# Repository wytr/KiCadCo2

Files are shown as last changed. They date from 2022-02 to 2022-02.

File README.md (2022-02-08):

# KiCadCo2

# ESP 12-F | MH-Z19C | CO2 INDICATOR

Schematic [here](https://github.com/wytr/KiCadCo2/blob/master/schematic_pdf/ESP8266_12F_BASIC.pdf)

Assembly [here](https://github.com/wytr/KiCadCo2/blob/master/Board2Pdf/ESP8266_12F_BASIC-Assembly.pdf)

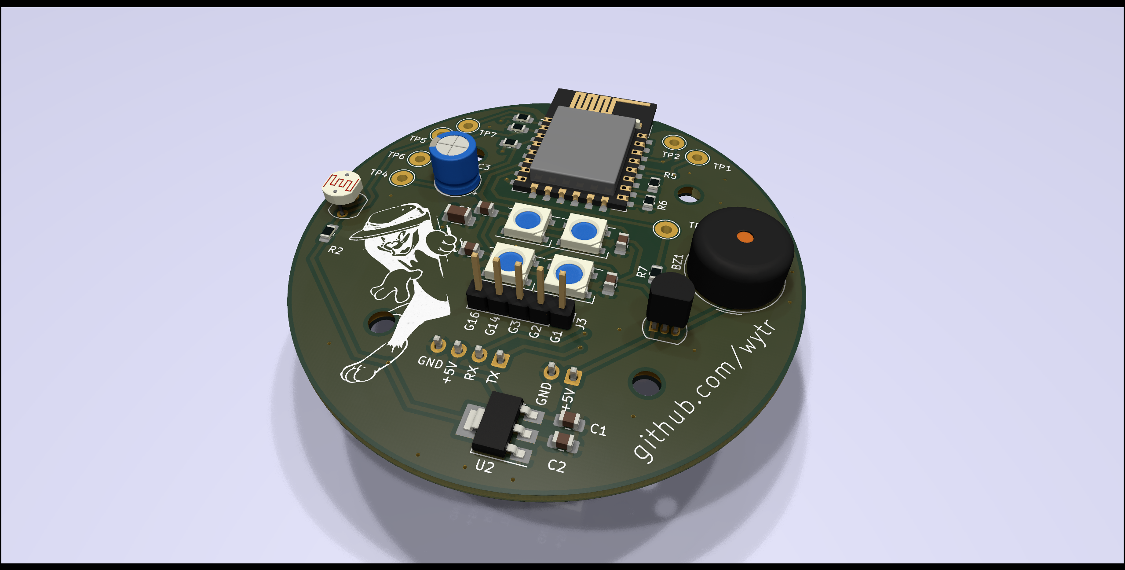
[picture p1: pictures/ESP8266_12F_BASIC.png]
raytraced pcb


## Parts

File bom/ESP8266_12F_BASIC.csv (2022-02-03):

Source: | C:\Users\mrtn\Documents\KiCad\6.0\projects\ESP8266_12F_BASIC\ESP8266_12F_BASIC.kicad_sch
Date: | 03.02.2022 03:34:38
Tool: | Eeschema (6.0.1)
Generator: | C:\Program Files\KiCad\6.0\bin\scripting\plugins/bom_csv_grouped_by_value.py
Component Count: | 35
Individual Components:
Item | Qty | Reference(s) | Value | LibPart | Footprint | Datasheet
 |  | BZ1 | Buzzer | Device:Buzzer | Buzzer_Beeper:Buzzer_TDK_PS1240P02BT_D12.2mm_H6.5mm | ~
 |  | C1 | 100nF | Device:C_Small | Capacitor_SMD:C_0805_2012Metric_Pad1.18x1.45mm_HandSolder | ~
 |  | C2 | 100nF | Device:C_Small | Capacitor_SMD:C_0805_2012Metric_Pad1.18x1.45mm_HandSolder | ~
 |  | C3 | 10uF | Device:C | Capacitor_THT:CP_Radial_D6.3mm_P2.50mm | ~
 |  | C5 | 100nF | Device:C_Small | Capacitor_SMD:C_0805_2012Metric_Pad1.18x1.45mm_HandSolder | ~
 |  | C6 | 100nF | Device:C_Small | Capacitor_SMD:C_0805_2012Metric_Pad1.18x1.45mm_HandSolder | ~
 |  | C7 | 100nF | Device:C_Small | Capacitor_SMD:C_0805_2012Metric_Pad1.18x1.45mm_HandSolder | ~
 |  | C8 | 100nF | Device:C_Small | Capacitor_SMD:C_0805_2012Metric_Pad1.18x1.45mm_HandSolder | ~
 |  | D1 | WS2812B | LED:WS2812B | LED_SMD:LED_WS2812B_PLCC4_5.0x5.0mm_P3.2mm | https://cdn-shop.adafruit.com/datasheets/WS2812B.pdf
 |  | D2 | WS2812B | LED:WS2812B | LED_SMD:LED_WS2812B_PLCC4_5.0x5.0mm_P3.2mm | https://cdn-shop.adafruit.com/datasheets/WS2812B.pdf
 |  | D3 | WS2812B | LED:WS2812B | LED_SMD:LED_WS2812B_PLCC4_5.0x5.0mm_P3.2mm | https://cdn-shop.adafruit.com/datasheets/WS2812B.pdf
 |  | D4 | WS2812B | LED:WS2812B | LED_SMD:LED_WS2812B_PLCC4_5.0x5.0mm_P3.2mm | https://cdn-shop.adafruit.com/datasheets/WS2812B.pdf
 |  | H1 | MountingHole | Mechanical:MountingHole | MountingHole:MountingHole_3.2mm_M3 | ~
 |  | H2 | MountingHole | Mechanical:MountingHole | MountingHole:MountingHole_3.2mm_M3 | ~
 |  | H3 | MountingHole | Mechanical:MountingHole | MountingHole:MountingHole_3.2mm_M3 | ~
 |  | H4 | MountingHole | Mechanical:MountingHole | MountingHole:MountingHole_3.2mm_M3 | ~
 |  | J1 | Conn_01x02_Male | Connector:Conn_01x02_Male | Connector_JST:JST_XH_B2B-XH-A_1x02_P2.50mm_Vertical | ~
 |  | J2 | Conn_01x04_Male | Connector:Conn_01x04_Male | Connector_JST:JST_XH_B4B-XH-A_1x04_P2.50mm_Vertical | ~
 |  | Q1 | BC547 | Transistor_BJT:BC547 | Package_TO_SOT_THT:TO-92_Inline | https://www.onsemi.com/pub/Collateral/BC550-D.pdf
 |  | R1 | R_Photo | Device:R_Photo | OptoDevice:R_LDR_5.1x4.3mm_P3.4mm_Vertical | ~
 |  | R2 | 100k | Device:R | Resistor_SMD:R_0805_2012Metric_Pad1.20x1.40mm_HandSolder | ~
 |  | R3 | 10k | Device:R_Small | Resistor_SMD:R_0805_2012Metric_Pad1.20x1.40mm_HandSolder | ~
 |  | R4 | 10k | Device:R_Small | Resistor_SMD:R_0805_2012Metric_Pad1.20x1.40mm_HandSolder | ~
 |  | R5 | 10k | Device:R_Small | Resistor_SMD:R_0805_2012Metric_Pad1.20x1.40mm_HandSolder | ~
 |  | R6 | 10k | Device:R_Small | Resistor_SMD:R_0805_2012Metric_Pad1.20x1.40mm_HandSolder | ~
 |  | R7 | 100R | Device:R_Small | Resistor_SMD:R_0805_2012Metric_Pad1.20x1.40mm_HandSolder | ~
 |  | TP1 | TestPoint | Connector:TestPoint | TestPoint:TestPoint_THTPad_D3.0mm_Drill1.5mm | ~
 |  | TP2 | TestPoint | Connector:TestPoint | TestPoint:TestPoint_THTPad_D3.0mm_Drill1.5mm | ~
 |  | TP3 | TestPoint | Connector:TestPoint | TestPoint:TestPoint_THTPad_D3.0mm_Drill1.5mm | ~
 |  | TP4 | TestPoint | Connector:TestPoint | TestPoint:TestPoint_THTPad_D3.0mm_Drill1.5mm | ~
 |  | TP5 | TestPoint | Connector:TestPoint | TestPoint:TestPoint_THTPad_D3.0mm_Drill1.5mm | ~
 |  | TP6 | TestPoint | Connector:TestPoint | TestPoint:TestPoint_THTPad_D3.0mm_Drill1.5mm | ~
 |  | TP7 | TestPoint | Connector:TestPoint | TestPoint:TestPoint_THTPad_D3.0mm_Drill1.5mm | ~
 |  | U1 | ESP-12F | RF_Module:ESP-12F | RF_Module:ESP-12E | http://wiki.ai-thinker.com/_media/esp8266/esp8266_series_modules_user_manual_v1.1.pdf
 |  | U2 | AP1117-33 | Regulator_Linear:AP1117-33 | Package_TO_SOT_SMD:SOT-223-3_TabPin2 | http://www.diodes.com/datasheets/AP1117.pdf
Collated Components:
Item | Qty | Reference(s) | Value | LibPart | Footprint | Datasheet
1 | 1 | BZ1 | Buzzer | Device:Buzzer | Buzzer_Beeper:Buzzer_TDK_PS1240P02BT_D12.2mm_H6.5mm | ~
2 | 6 | C1, C2, C5, C6, C7, C8 | 100nF | Device:C_Small | Capacitor_SMD:C_0805_2012Metric_Pad1.18x1.45mm_HandSolder | ~
3 | 1 | C3 | 10uF | Device:C | Capacitor_THT:CP_Radial_D6.3mm_P2.50mm | ~
4 | 4 | D1, D2, D3, D4 | WS2812B | LED:WS2812B | LED_SMD:LED_WS2812B_PLCC4_5.0x5.0mm_P3.2mm | https://cdn-shop.adafruit.com/datasheets/WS2812B.pdf
5 | 4 | H1, H2, H3, H4 | MountingHole | Mechanical:MountingHole | MountingHole:MountingHole_3.2mm_M3 | ~
6 | 1 | J1 | Conn_01x02_Male | Connector:Conn_01x02_Male | Connector_JST:JST_XH_B2B-XH-A_1x02_P2.50mm_Vertical | ~
7 | 1 | J2 | Conn_01x04_Male | Connector:Conn_01x04_Male | Connector_JST:JST_XH_B4B-XH-A_1x04_P2.50mm_Vertical | ~
8 | 1 | Q1 | BC547 | Transistor_BJT:BC547 | Package_TO_SOT_THT:TO-92_Inline | https://www.onsemi.com/pub/Collateral/BC550-D.pdf
9 | 1 | R1 | R_Photo | Device:R_Photo | OptoDevice:R_LDR_5.1x4.3mm_P3.4mm_Vertical | ~
10 | 1 | R2 | 100k | Device:R | Resistor_SMD:R_0805_2012Metric_Pad1.20x1.40mm_HandSolder | ~
11 | 4 | R3, R4, R5, R6 | 10k | Device:R_Small | Resistor_SMD:R_0805_2012Metric_Pad1.20x1.40mm_HandSolder | ~
12 | 1 | R7 | 100R | Device:R_Small | Resistor_SMD:R_0805_2012Metric_Pad1.20x1.40mm_HandSolder | ~
13 | 7 | TP1, TP2, TP3, TP4, TP5, TP6, TP7 | TestPoint | Connector:TestPoint | TestPoint:TestPoint_THTPad_D3.0mm_Drill1.5mm | ~
14 | 1 | U1 | ESP-12F | RF_Module:ESP-12F | RF_Module:ESP-12E | http://wiki.ai-thinker.com/_media/esp8266/esp8266_series_modules_user_manual_v1.1.pdf
15 | 1 | U2 | AP1117-33 | Regulator_Linear:AP1117-33 | Package_TO_SOT_SMD:SOT-223-3_TabPin2 | http://www.diodes.com/datasheets/AP1117.pdf

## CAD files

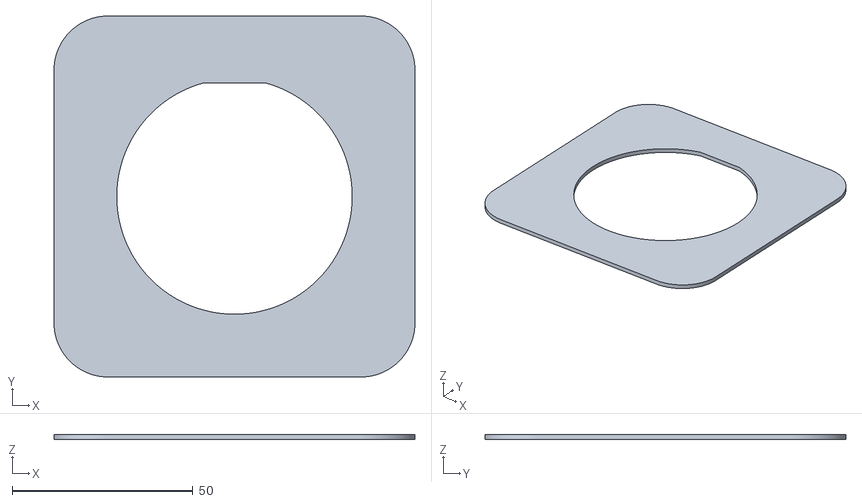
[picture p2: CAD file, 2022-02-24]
3D_MODEL/Schablonenhalter.stl
100.0 x 100.0 x 1.50

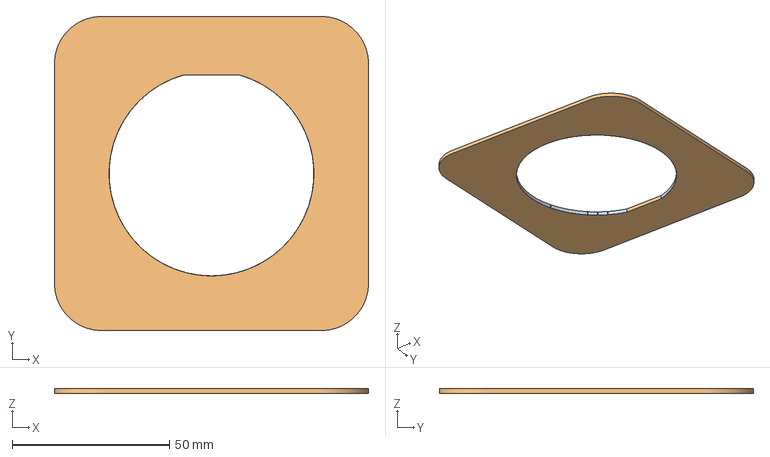
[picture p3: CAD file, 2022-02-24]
3D_MODEL/ESP8266_12F_CO2_Schablonenhalter.FCStd
100.0 x 100.0 x 1.50 mm
Part (Meshed)

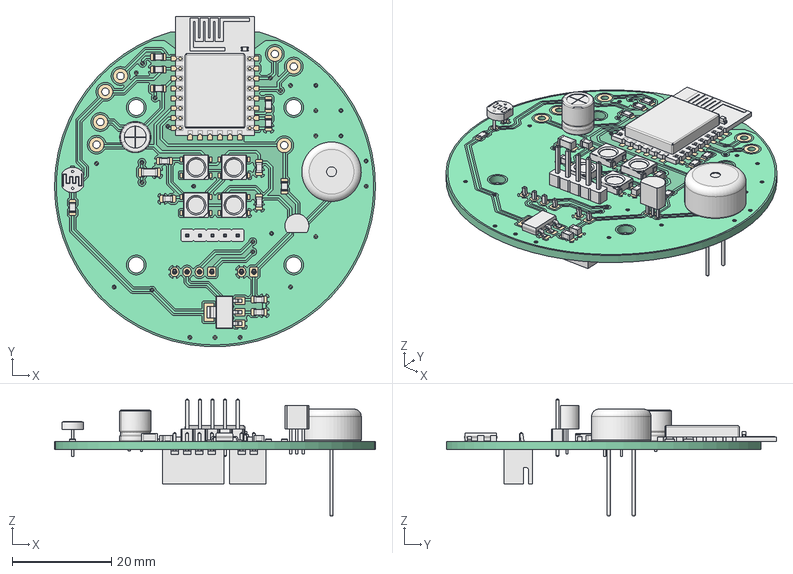
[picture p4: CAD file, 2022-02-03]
3D_MODEL/ESP8266_12F_CO2.FCStd
64.7 x 66.5 x 23.5 mm
Pcb_7f20
topPads_7f20
topTracks_7f20
topZones_7f20
botPads_7f20
botTracks_7f20
botZones_7f20
R4_R_0805_2012Metric_5a90df88a964 x 7
D2_LED_WS2812B_PLCC4_50x50mm_P32mm_d242eb3a4c77 x 4
U2_SOT_223_ae3f01b72ff0
C4_C_1206_3216Metric_41223b271484
C3_CP_Radial_D63mm_P250mm_c3d035a31bd0
J3_PinHeader_1x05_P254mm_Vertical_2d5c8401fe23
C5_C_0805_2012Metric_72cb813c9184 x 6
R1_R_LDR_5.1x4.3mm_P3.4mm_Vertical_380525c35caf
Q1_TO-92_Inline_Narrow_ab2950cb5ffa
U1_ESP_12E001_cp_c43c0a32ca6d
BZ1_Buzzer_TDK_PS1240P02BT_D122mm_H65mm_4825805f86ed
J1_JST_B2B_XH_A_3523783868fa
J2_JST_B4B_XH_A_3fdb70fe1788

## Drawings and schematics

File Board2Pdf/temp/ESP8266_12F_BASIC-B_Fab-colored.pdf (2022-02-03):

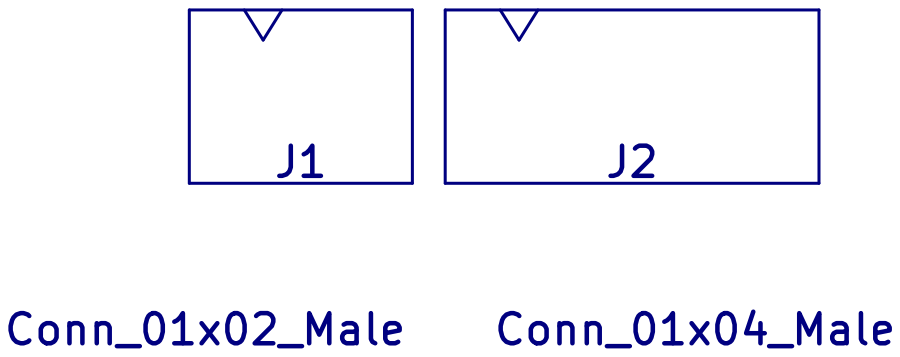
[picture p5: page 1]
D Date: KiCad E.D.A. kicad (6.0.1) Size: A4; Rev:; Id: 1/1 Title:; File: ESP8266_12F_BASIC.kicad_pcb; Sheet: Assembly; Conn_01x02_Male; Conn_01x04_Male

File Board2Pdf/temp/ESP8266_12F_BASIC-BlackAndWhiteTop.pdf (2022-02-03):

1 | 2 | 3 | 4 | 5 | 6

A

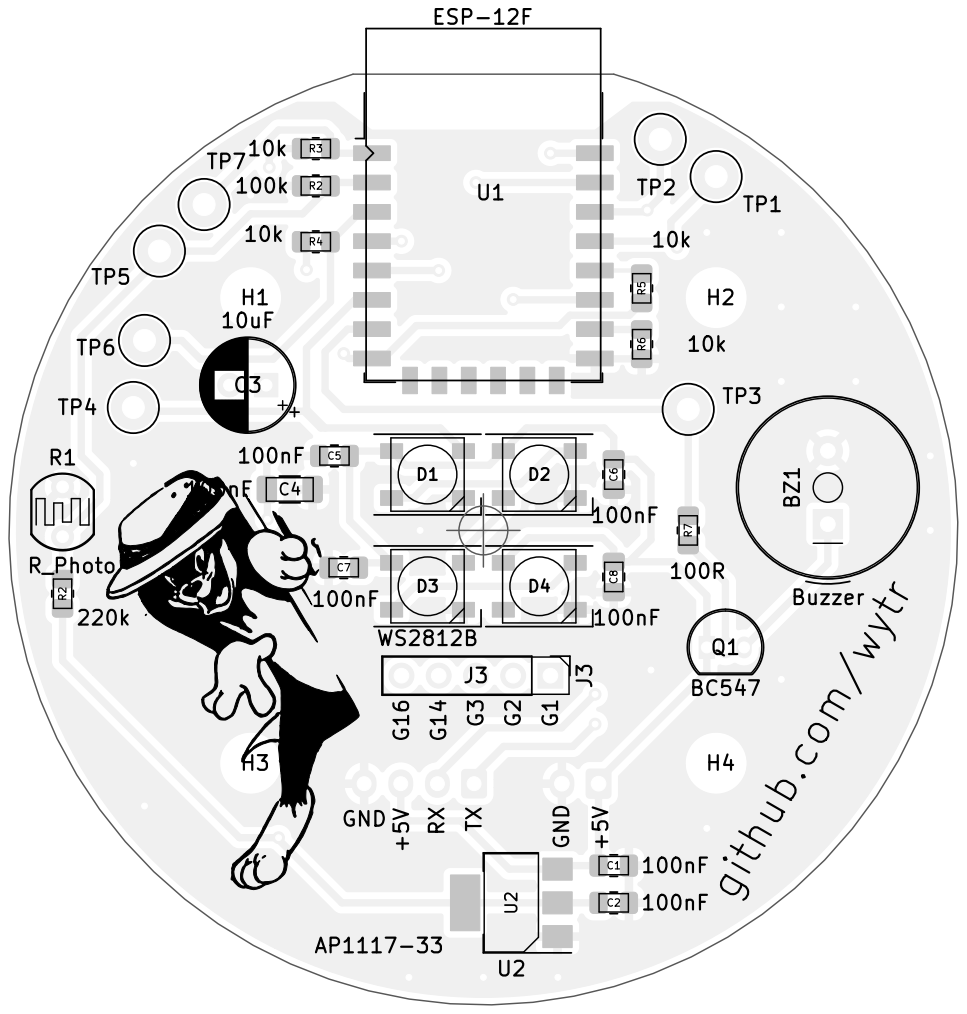
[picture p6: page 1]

G1 RXTX G3 G2 G14 GND github.com/wytr +5V G16 +5V GND

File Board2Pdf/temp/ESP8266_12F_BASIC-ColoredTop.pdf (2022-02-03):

1 | 2 | 3 | 4 | 5 | 6

A

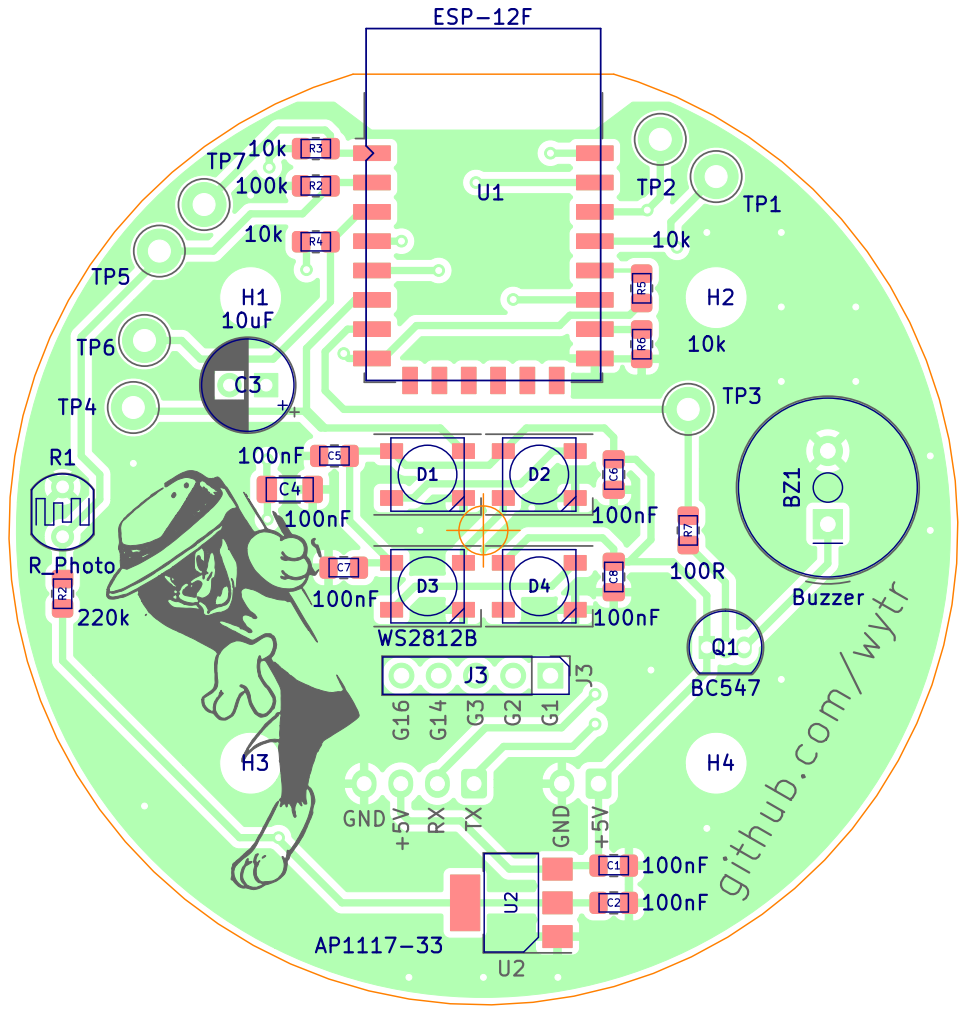
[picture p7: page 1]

G1 RXTX G3 G2 G14 GND github.com/wytr +5V G16 +5V GND

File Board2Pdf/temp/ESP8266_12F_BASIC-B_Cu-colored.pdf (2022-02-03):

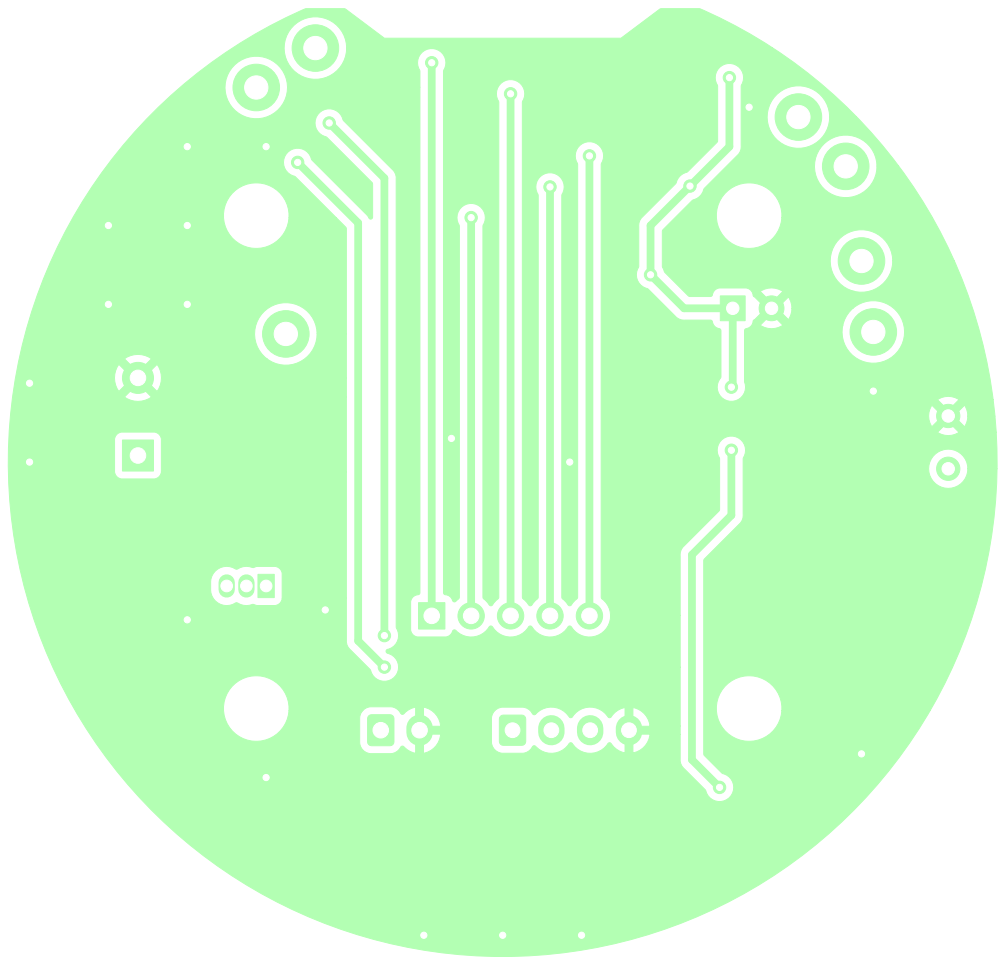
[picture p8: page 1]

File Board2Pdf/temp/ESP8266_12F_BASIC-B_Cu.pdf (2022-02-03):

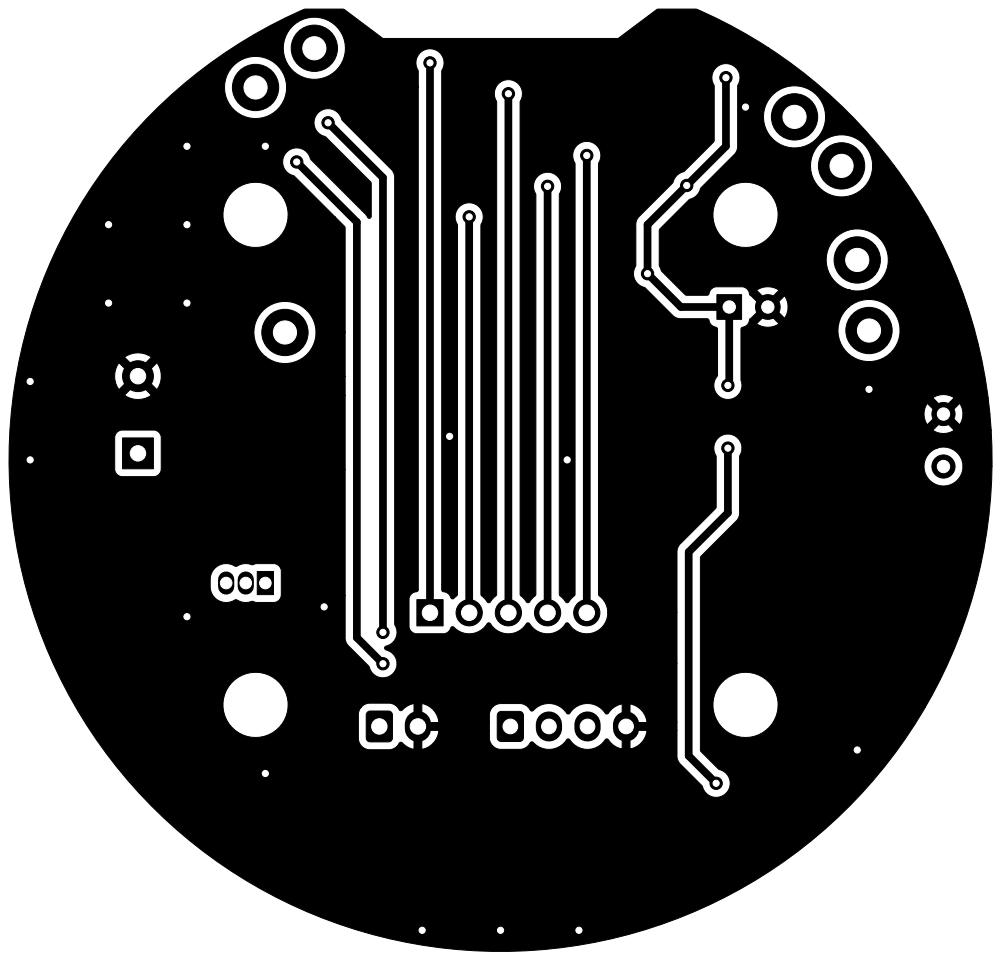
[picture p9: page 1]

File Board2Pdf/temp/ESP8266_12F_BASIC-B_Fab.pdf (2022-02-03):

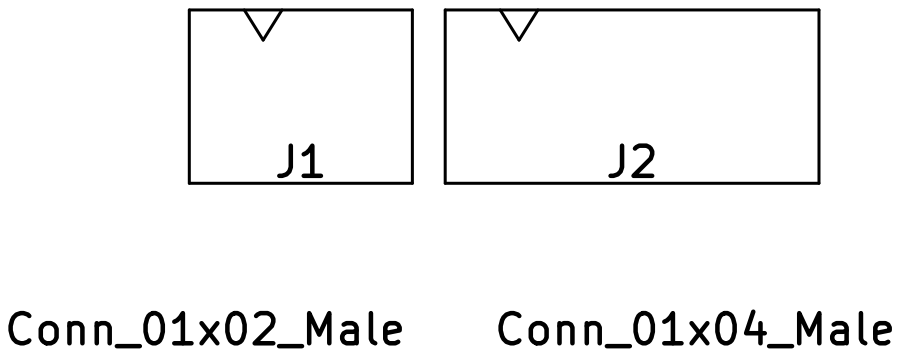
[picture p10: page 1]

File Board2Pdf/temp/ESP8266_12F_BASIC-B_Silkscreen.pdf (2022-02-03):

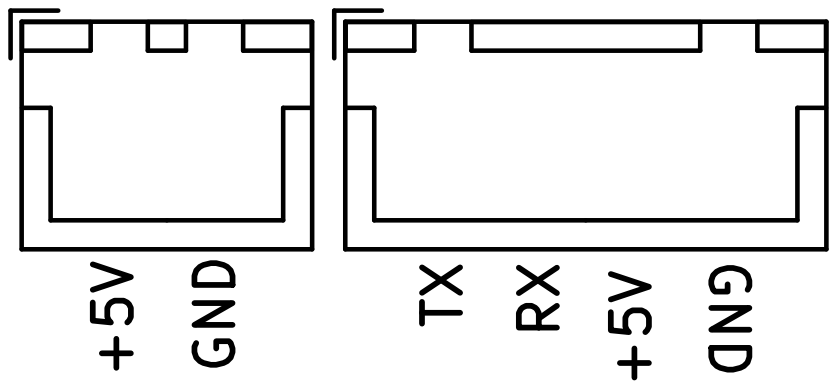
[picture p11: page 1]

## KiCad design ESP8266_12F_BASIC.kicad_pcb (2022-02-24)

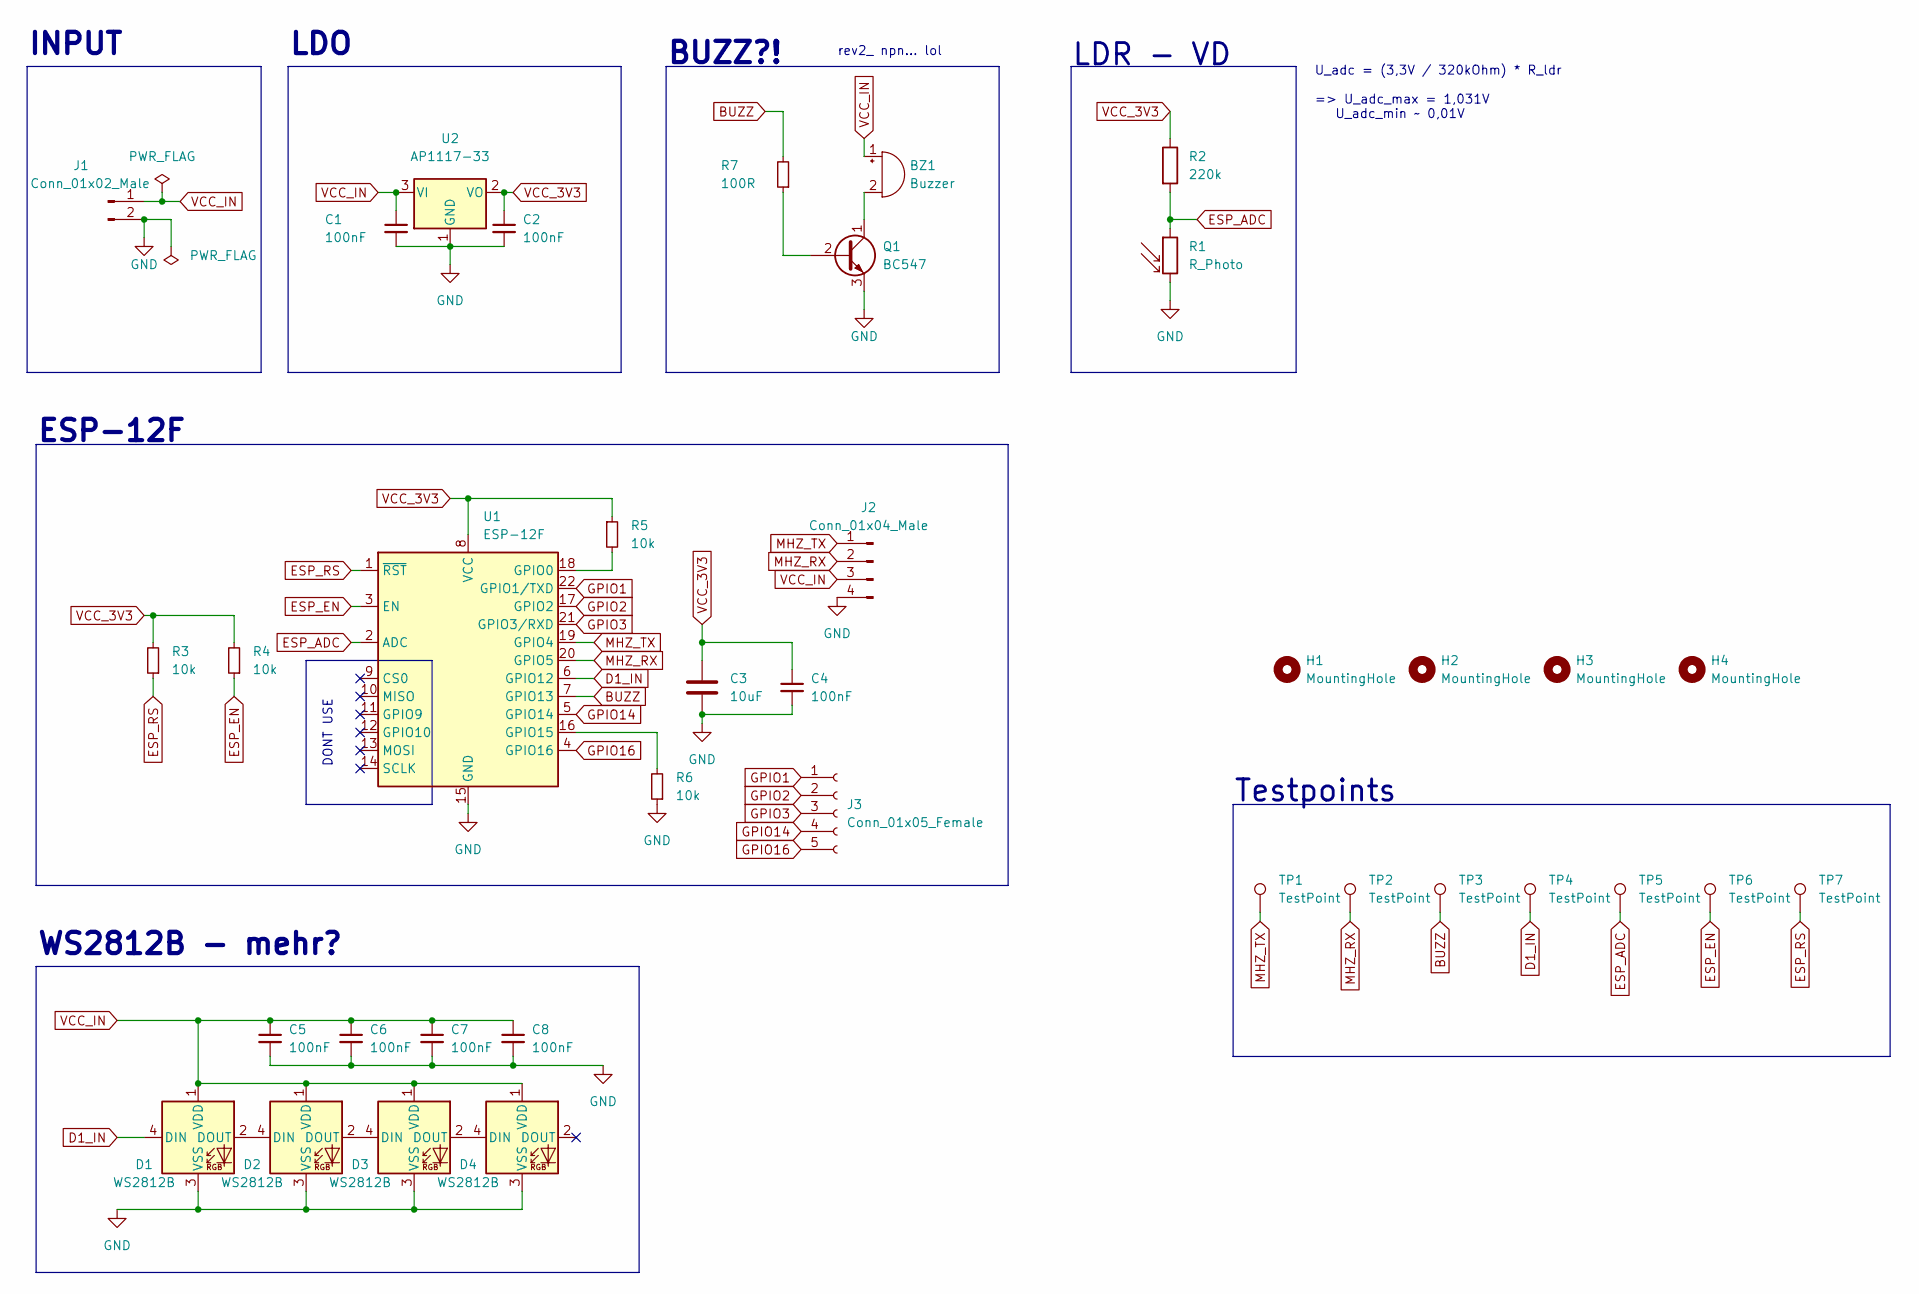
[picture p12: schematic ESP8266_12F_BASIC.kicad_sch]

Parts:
BZ1: Buzzer; Buzzer_TDK_PS1240P02BT_D12.2mm_H6.5mm
C1, C2, C5, C6, C7, C8: 100nF; C_0805_2012Metric_Pad1.18x1.45mm_HandSolder
C3: 10uF; CP_Radial_D6.3mm_P2.50mm
C4: 100nF; C_1206_3216Metric_Pad1.33x1.80mm_HandSolder
D1, D2, D3, D4: WS2812B; LED_WS2812B_PLCC4_5.0x5.0mm_P3.2mm
H1, H2, H3, H4: MountingHole; MountingHole_3.2mm_M3
J1: Conn_01x02_Male; JST_XH_B2B-XH-A_1x02_P2.50mm_Vertical
J2: Conn_01x04_Male; JST_XH_B4B-XH-A_1x04_P2.50mm_Vertical
J3: Conn_01x05_Female; PinHeader_1x05_P2.54mm_Vertical
Q1: BC547; TO-92_Inline
R1: R_Photo; R_LDR_5.1x4.3mm_P3.4mm_Vertical
R2: 220k; R_0805_2012Metric_Pad1.20x1.40mm_HandSolder
R3, R4, R5, R6: 10k; R_0805_2012Metric_Pad1.20x1.40mm_HandSolder
R7: 100R; R_0805_2012Metric_Pad1.20x1.40mm_HandSolder
TP1, TP2, TP3, TP4, TP5, TP6, TP7: TestPoint; TestPoint_THTPad_D3.0mm_Drill1.5mm
U1: ESP-12F; ESP-12E
U2: AP1117-33; SOT-223-3_TabPin2

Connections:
BUZZ: R7.2, TP3.1, U1.7 (GPIO13)
D1_IN: D1.4 (DIN), TP4.1, U1.6 (GPIO12)
ESP_ADC: R1.1, R2.2, TP5.1, U1.2 (ADC); also elsewhere on the board
ESP_EN: R4.1, TP6.1, U1.3 (EN)
ESP_RS: R3.1, TP7.1, U1.1 (~RST)
GND: C1.2, C2.2, C3.2, C4.2, C5.2, C6.2, C7.2, C8.2, D1.3 (VSS), D2.3 (VSS), D3.3 (VSS), D4.3 (VSS), J1.2, J2.4, Q1.3 (E), R1.2, R6.1, U1.15 (GND), U2.1 (GND); also elsewhere on the board
GPIO1: J3.1, U1.22 (GPIO1/TXD)
GPIO2: J3.2, U1.17 (GPIO2)
GPIO3: J3.3, U1.21 (GPIO3/RXD)
GPIO14: J3.4, U1.5 (GPIO14)
GPIO16: J3.5, U1.4 (GPIO16)
MHZ_RX: J2.2, TP2.1, U1.20 (GPIO5)
MHZ_TX: J2.1, TP1.1, U1.19 (GPIO4)
unnamed: BZ1.2 (+), Q1.1 (C)
unnamed: D1.2 (DOUT), D2.4 (DIN)
unnamed: D2.2 (DOUT), D3.4 (DIN)
unnamed: D3.2 (DOUT), D4.4 (DIN)
unnamed: R5.2, U1.18 (GPIO0)
unnamed: R6.2, U1.16 (GPIO15)
unnamed: Q1.2 (B), R7.1
VCC_3V3: C2.1, C3.1, C4.1, R2.1, R3.2, R4.2, R5.1, U1.8 (VCC), U2.2 (VO)
VCC_IN: BZ1.1 (-), C1.1, C5.1, C6.1, C7.1, C8.1, D1.1 (VDD), D2.1 (VDD), D3.1 (VDD), D4.1 (VDD), J1.1, J2.3, U2.3 (VI)

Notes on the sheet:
LDR - VD
DONT USE
INPUT
WS2812B - mehr?
rev2_ npn... lol
U_adc = (3,3V / 320kOhm) * R_ldr => U_adc_max = 1,031V U_adc_min ~ 0,01V
LDO
ESP-12F
BUZZ?!
Testpoints

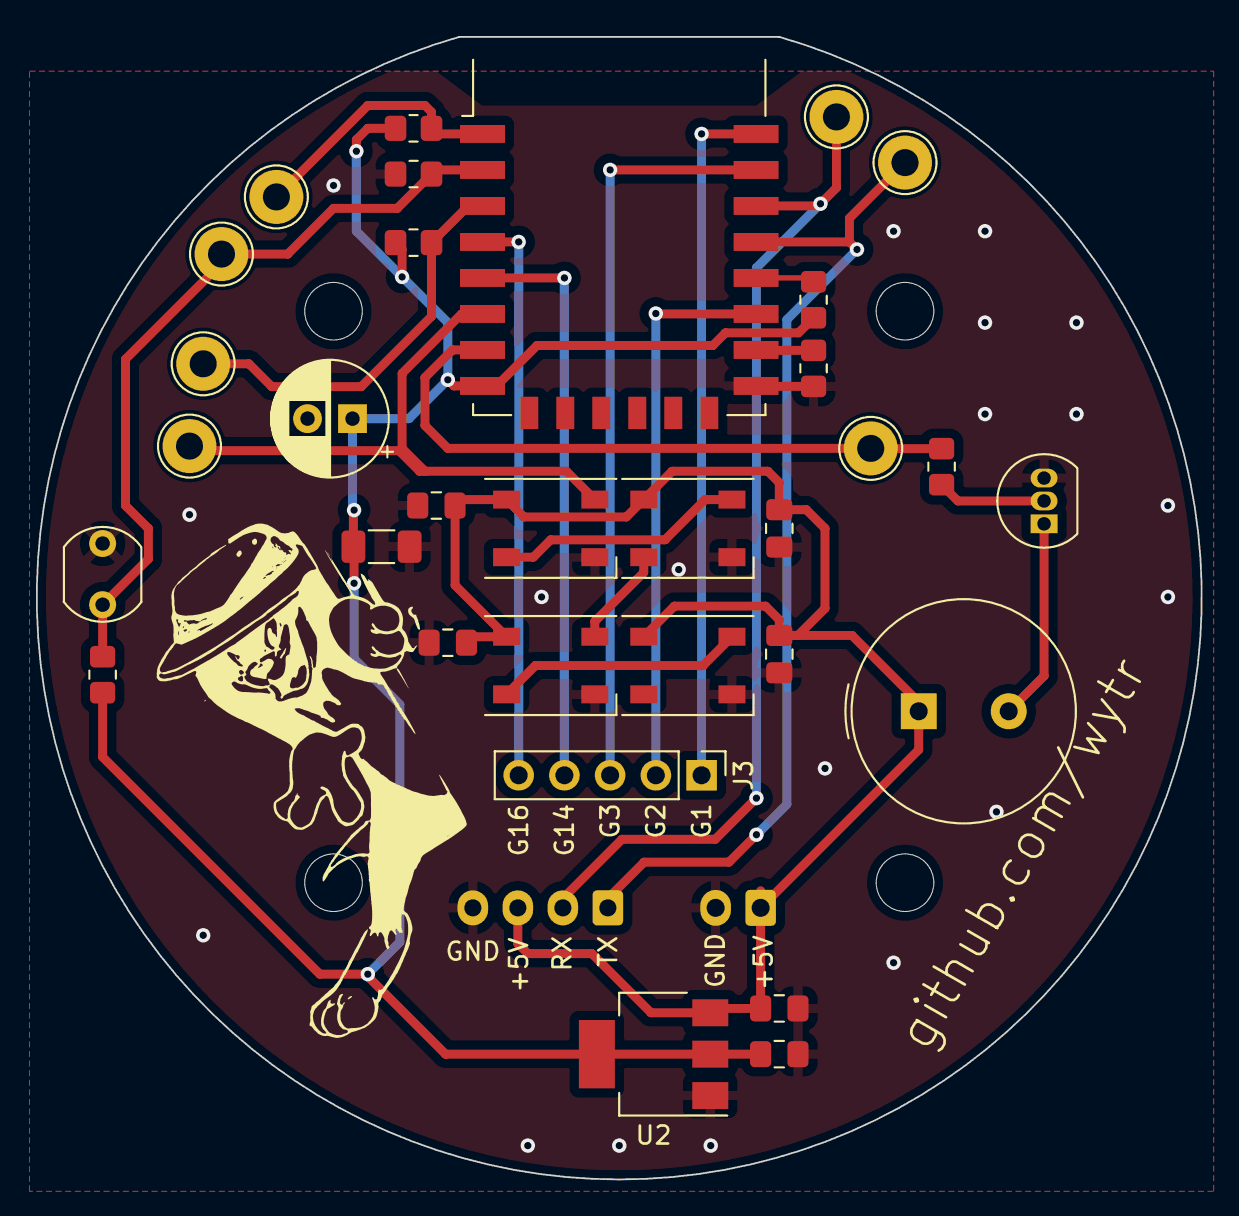
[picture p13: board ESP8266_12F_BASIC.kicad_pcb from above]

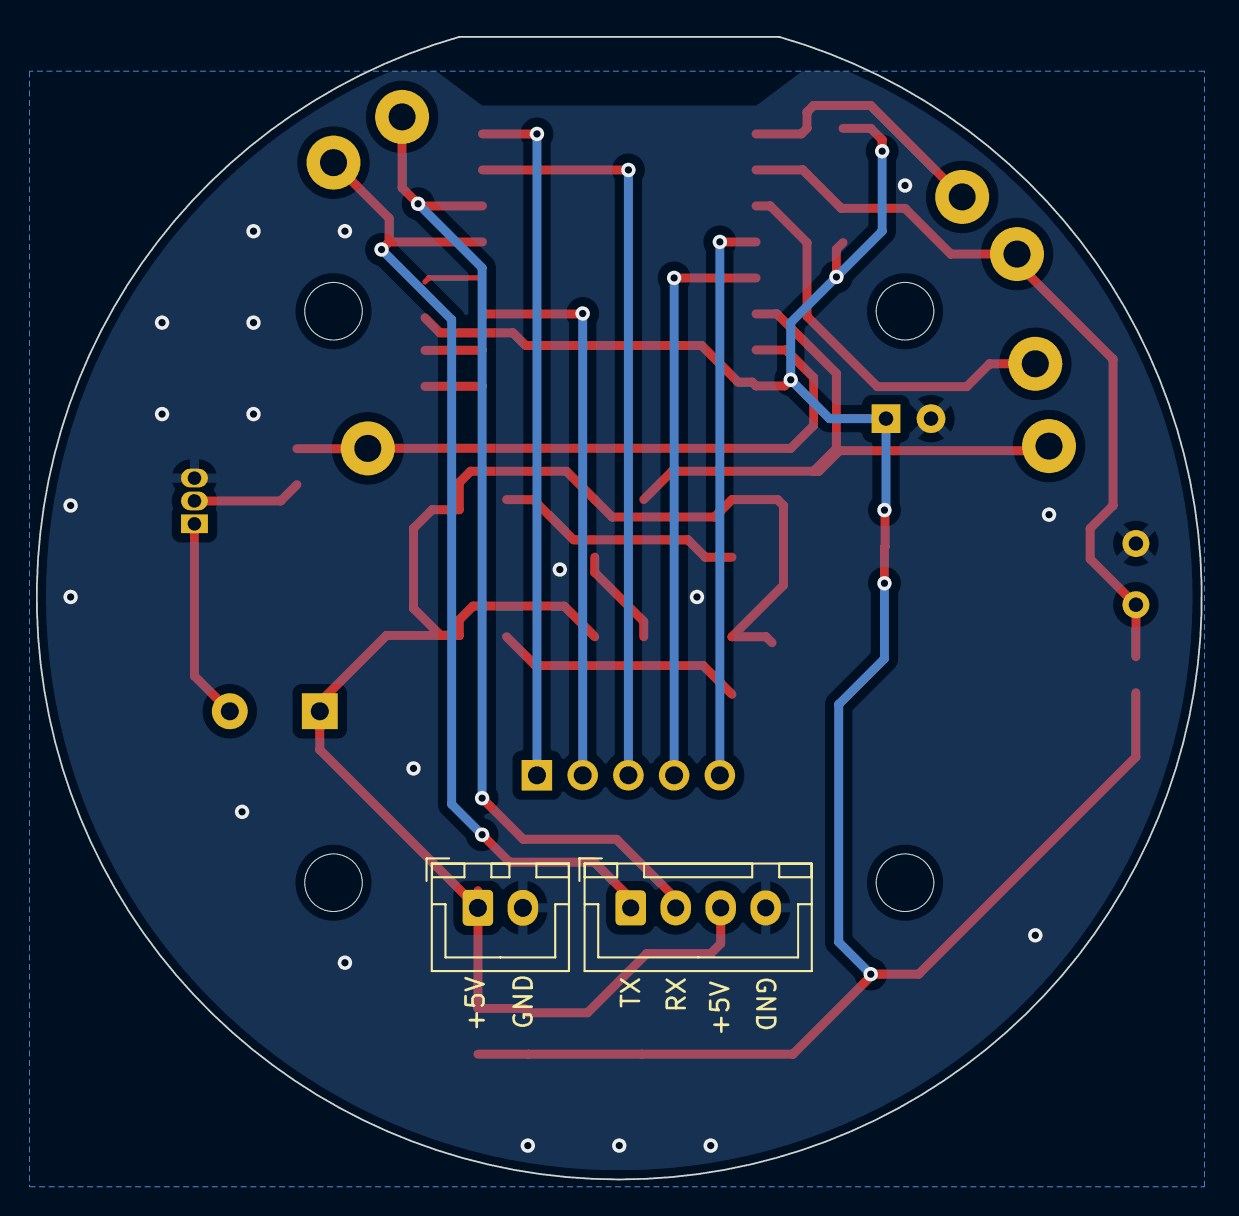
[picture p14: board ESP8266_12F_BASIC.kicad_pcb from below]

Board: 2 copper layers, 64.7 x 63.5 mm, 38 parts (2 on the bottom side), 22 nets.

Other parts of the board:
R2#2: 100k; R_0805_2012Metric_Pad1.20x1.40mm_HandSolder

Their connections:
ESP_ADC: R2#2.1; also elsewhere on the board
GND: R2#2.2; also elsewhere on the board

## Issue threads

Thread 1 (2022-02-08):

gpio 2

wytr, 2022-02-08:
GPIO 2 is not connected to HIGH (running mode)

wytr, 2022-02-08:
hotfix, added R8, removed connection to jst header

wytr, 2022-02-08:
reverting to last commit:

"Note: you don’t have to add an external pull-up resistor to GPIO2, the internal one is enabled at boot."

->https://tttapa.github.io/ESP8266/Chap04%20-%20Microcontroller.html

Closed 2022-02-08.

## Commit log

2022-02-03 kicad test
    [ESP8266_12F_BASIC.csv, ESP8266_12F_BASIC.kicad_pcb, ESP8266_12F_BASIC.kicad_sch]
2022-02-03 fixed header position
    [ESP8266_12F_BASIC.csv, ESP8266_12F_BASIC.kicad_pcb, ESP8266_12F_BASIC.kicad_sch]
2022-02-03 added silkscreen for header
    [ESP8266_12F_BASIC.kicad_pcb]
2022-02-03 added gerber pdf and pictures
    [ESP8266_12F_BASIC-B_Cu.gbr, ESP8266_12F_BASIC-B_Mask.gbr, ESP8266_12F_BASIC-B_Paste.gbr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]
2022-02-03 added assembly picture
2022-02-03 major fixes
    [ESP8266_12F_BASIC.kicad_pcb, ESP8266_12F_BASIC.kicad_sch, ESP8266_12F_CO2.FCStd]
2022-02-03 caps added and move also added new picture
    [ESP8266_12F_BASIC.kicad_pcb, ESP8266_12F_BASIC.kicad_sch]
2022-02-03 updated schematic pdf
2022-02-03 updated gerber
    [ESP8266_12F_BASIC-B_Cu.gbr, ESP8266_12F_BASIC-B_Mask.gbr, ESP8266_12F_BASIC-B_Paste.gbr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]
2022-02-03 added fabrication files
    [ESP8266_12F_BASIC.kicad_pcb]
2022-02-08 old state no hotfix
    [ESP8266_12F_BASIC.kicad_pcb, ESP8266_12F_BASIC.kicad_sch]
2022-02-08 weird shit
    [ESP8266_12F_BASIC.kicad_pcb]
2022-02-24 fixed stupid npn error
    [ESP8266_12F_BASIC.kicad_pcb, ESP8266_12F_BASIC.kicad_sch, ESP8266_12F_CO2_Schablonenhalter.FCStd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]
